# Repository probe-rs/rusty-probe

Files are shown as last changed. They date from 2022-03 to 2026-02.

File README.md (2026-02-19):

# The Rusty Probe

This is an open hardware probe for the Serial Wire Debug (SWD) and JTAG protocol.
Based on the RP2040 MCU.

## Firmware

The firmware is available [here](https://github.com/probe-rs/rusty-probe-firmware) and is open-source.

## Features

- The 10-pin Cortex-Debug connector is used.
- The programming connector is the Tag Connect TC2030, however for just loading firmware the USB bootloader is recommended.
- Castellated vias for all programming pins, power and 2 GPIOs.
- USB-C connector.
- Target 5V and `Vtarget` is protected with an diode circuit to not have current flow from the target to the host.
- The probe support 1.8v - 3.3v signal voltage and can track `Vtarget`.
- The key pin on the Cortex-Debug can be connected to the protected 5V.

The schematic can be found in the GitHub actions, full production files are generated for each commit.

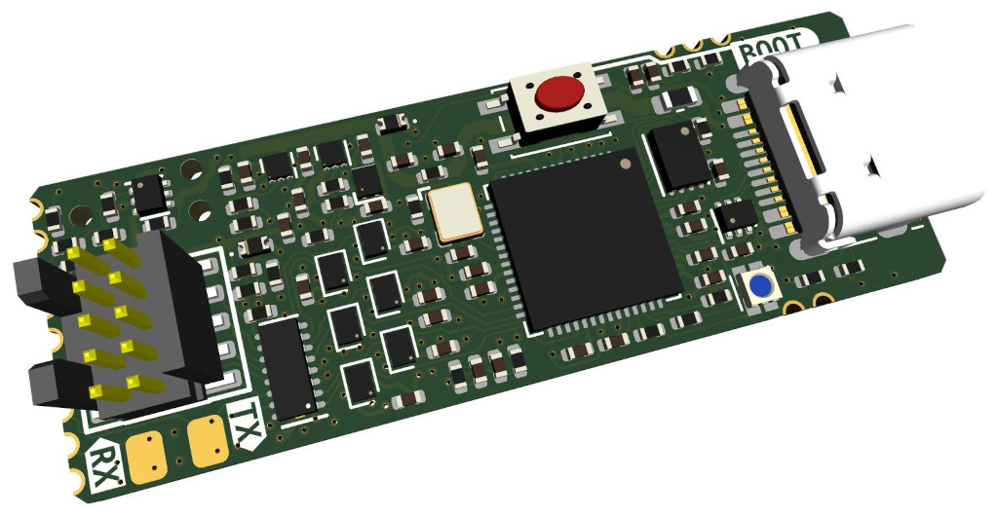
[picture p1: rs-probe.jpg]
probe


## Comparison

Here is a small comparison with a few different probes:

| | Rusty Probe | PicoProbe | Raspberry Pi Debug Probe | STLinkV3 | JLink |
|---|---|---|---|---|---|
| Max speed | 62 MHz | 10 MHz | 10 MHz | 24 MHz | 15 MHz |
| Target interface support| JTAG, SWD, SWO, UART | SWD | SWD, UART | JTAG, SWD, UART, SWO <br>Note: STM8/32 chips only | JTAG, SWD, SWO|
| IO voltage control | 1.8-3.3V | 3.3V | 1.8-3.3V | 1.6-3.3V | 1.6-3.3V somtimes  |
| Type | Open Source & Hardware | Open Source | Open Source Software | Proprietary | Proprietary |
| Language | Rust | C | C | C | C |
| Protocol | CMSIS-DAP | CMSIS-DAP | CMSIS-DAP | Proprietary | CMSIS-DAP |
| Programming connector | Cortex-M Debug 10p | - | JST | Cortex-M Debug 14p | Cortex-M Debug 10p |
| USB speed | 12 MBit/s | 12 MBit/s | 12 MBit/s | 480 MBit/s | 12 MBit/s |

## Where to buy

The probe is available in the [probe-rs shop](https://shop.probe.rs/). But you are free to build one yourself as well!

## License

This work is licensed under [CERN-OHL-P](cern_ohl_p_v2.txt).

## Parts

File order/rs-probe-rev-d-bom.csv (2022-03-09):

Source: | /home/emifre/Git/rs-probe/rs-probe.kicad_sch
Date: | Wed 09 Mar 2022 02:24:04 PM CET
Tool: | Eeschema (6.0.2)
Generator: | /usr/share/kicad/plugins/bom_csv_grouped_by_value.py
Component Count: | 87
Individual Components:
Item | Qty | Reference(s) | Value | LibPart | Footprint | Datasheet | MFPN | Manufacturer | Tolerance
 |  | C1 | 0.1u | Device:C_Small | passive:C_0402 | ~ |  |  | 25V, X7R
 |  | C2 | 2.2u | Device:C_Small | passive:C_0402 | ~ |  |  | 10V, X5R
 |  | C3 | 2.2u | Device:C_Small | passive:C_0402 | ~ |  |  | 10V, X5R
 |  | C4 | 2.2u | Device:C_Small | passive:C_0402 | ~ |  |  | 10V, X5R
 |  | C5 | 0.1u | Device:C_Small | passive:C_0402 | ~ |  |  | 25V, X7R
 |  | C6 | 2.2u | Device:C_Small | passive:C_0402 | ~ |  |  | 10V, X5R
 |  | C7 | 0.1u | Device:C_Small | passive:C_0402 | ~ |  |  | 25V, X7R
 |  | C8 | 0.1u | Device:C_Small | passive:C_0402 | ~ |  |  | 25V, X7R
 |  | C9 | 0.1u | Device:C_Small | passive:C_0402 | ~ |  |  | 25V, X7R
 |  | C10 | 0.1u | Device:C_Small | passive:C_0402 | ~ |  |  | 25V, X7R
 |  | C11 | 0.1u | Device:C_Small | passive:C_0402 | ~ |  |  | 25V, X7R
 |  | C12 | 0.1u | Device:C_Small | passive:C_0402 | ~ |  |  | 25V, X7R
 |  | C13 | 0.1u | Device:C_Small | passive:C_0402 | ~ |  |  | 25V, X7R
 |  | C14 | 0.1u | Device:C_Small | passive:C_0402 | ~ |  |  | 25V, X7R
 |  | C15 | 0.1u | Device:C_Small | passive:C_0402 | ~ |  |  | 25V, X7R
 |  | C16 | 0.1u | Device:C_Small | passive:C_0402 | ~ |  |  | 25V, X7R
 |  | C17 | 0.1u | Device:C_Small | passive:C_0402 | ~ |  |  | 25V, X7R
 |  | C18 | 0.1u | Device:C_Small | passive:C_0402 | ~ |  |  | 25V, X7R
 |  | C19 | 0.1u | Device:C_Small | passive:C_0402 | ~ |  |  | 25V, X7R
 |  | C20 | 0.1u | Device:C_Small | passive:C_0402 | ~ |  |  | 25V, X7R
 |  | C21 | 2.2u | Device:C_Small | passive:C_0402 | ~ |  |  | 10V, X5R
 |  | C22 | 0.1u | Device:C_Small | passive:C_0402 | ~ |  |  | 25V, X7R
 |  | C23 | 0.1u | Device:C_Small | passive:C_0402 | ~ |  |  | 25V, X7R
 |  | C24 | 2.2u | Device:C_Small | passive:C_0402 | ~ |  |  | 10V, X5R
 |  | C25 | 2.2u | Device:C_Small | passive:C_0402 | ~ |  |  | 10V, X5R
 |  | C26 | 2.2u | Device:C_Small | passive:C_0402 | ~ |  |  | 10V, X5R
 |  | C27 | 2.2u | Device:C_Small | passive:C_0402 | ~ |  |  | 10V, X5R
 |  | C28 | 0.1u | Device:C_Small | passive:C_0402 | ~ |  |  | 25V, X7R
 |  | D1 | LTST-C19HE1WT | Device:LED_RGBA | LED_SMD:LED_LiteOn_LTST-C19HE1WT | https://optoelectronics.liteon.com/upload/download/DS22-2008-0044/LTST-C19HE1WT.pdf | LTST-C19HE1WT or ‎IN-S66TBTRGB‎
 |  | D2 | 20V | Device:D_Zener_Small | Diode_SMD:D_SOD-123F | ~ | RBS2MM40CTR
 |  | F1 | Fuse_Small | Device:Fuse_Small | Fuse:Fuse_0603_1608Metric | https://www.bourns.com/docs/Product-Datasheets/mffsmf.pdf | MF-FSMF050X-2
 |  | J1 | USB_C_Receptacle_USB2.0 | Connector:USB_C_Receptacle_USB2.0 | connectors:USB_C_Receptacle_USB4105 | https://www.usb.org/sites/default/files/documents/usb_type-c.zip | C167321 (lcsc.com)
 |  | J2 | Castellated Vias | Connector:Conn_01x09_Female | connectors:1x9_1.5mm_castellated | ~
 |  | J3 | Castellated Vias | Connector:Conn_01x02_Female | connectors:1x2_1.5mm_castellated | ~
 |  | J4 | Castellated Vias | Connector:Conn_01x03_Female | connectors:1x3_1.5mm_castellated | ~
 |  | J5 | tag-connect-swd | connectors:tag-connect-swd | Connector:Tag-Connect_TC2030-IDC-NL_2x03_P1.27mm_Vertical | ~
 |  | J6 | Conn_01x01 | Connector_Generic:Conn_01x01 | connectors:pad_1.5x2.0mm | ~
 |  | J7 | Conn_01x01 | Connector_Generic:Conn_01x01 | connectors:pad_1.5x2.0mm | ~
 |  | J8 | Conn_01x01 | Connector_Generic:Conn_01x01 | connectors:pad_1.5x2.0mm | ~
 |  | J9 | Conn_01x01 | Connector_Generic:Conn_01x01 | connectors:pad_1.5x2.0mm | ~
 |  | Q1 | NTZD3155C or CMLDM3757-TR-PBFREE or DMC2400UV-7 or DMG1016VQ-7 | mosfet:NTZD3155C | sot:SOT-563 | https://www.onsemi.com/pub/Collateral/NTZD3155C-D.PDF
 |  | Q2 | NTZD3155C or CMLDM3757-TR-PBFREE or DMC2400UV-7 or DMG1016VQ-7 | mosfet:NTZD3155C | sot:SOT-563 | https://www.onsemi.com/pub/Collateral/NTZD3155C-D.PDF
 |  | R1 | 1k | Device:R_Small | passive:R_0402 | ~ |  |  | 1%
 |  | R2 | 1k | Device:R_Small | passive:R_0402 | ~ |  |  | 1%
 |  | R3 | 5.1k | Device:R_Small | passive:R_0402 | ~ |  |  | 1%
 |  | R4 | 5.1k | Device:R_Small | passive:R_0402 | ~ |  |  | 1%
 |  | R5 | 1k | Device:R_Small | passive:R_0402 | ~ |  |  | 1%
 |  | R6 | 1k | Device:R_Small | passive:R_0402 | ~ |  |  | 1%
 |  | R7 | 1k | Device:R_Small | passive:R_0402 | ~ |  |  | 1%
 |  | R8 | 1k | Device:R_Small | passive:R_0402 | ~ |  |  | 1%
 |  | R9 | 68k | Device:R_Small | passive:R_0402 | ~ |  |  | 1%
 |  | R10 | 68k | Device:R_Small | passive:R_0402 | ~ |  |  | 1%
 |  | R11 | 68k | Device:R_Small | passive:R_0402 | ~ |  |  | 1%
 |  | R12 | 47k | Device:R_Small | passive:R_0402 | ~ |  |  | 1%
 |  | R13 | 17.4k | Device:R_Small | passive:R_0402 | ~ |  |  | 1%
 |  | R14 | 47k | Device:R_Small | passive:R_0402 | ~ |  |  | 1%
 |  | R15 | 17.4k | Device:R_Small | passive:R_0402 | ~ |  |  | 1%
 |  | R16 | 68k | Device:R_Small | passive:R_0402 | ~ |  |  | 1%
 |  | R17 | 1k | Device:R_Small | passive:R_0402 | ~ |  |  | 1%
 |  | R18 | 68k | Device:R_Small | passive:R_0402 | ~ |  |  | 1%
 |  | R19 | 68k | Device:R_Small | passive:R_0402 | ~ |  |  | 1%
 |  | R20 | 5.1k | Device:R_Small | passive:R_0402 | ~ |  |  | 1%
 |  | R21 | 5.1k | Device:R_Small | passive:R_0402 | ~ |  |  | 1%
 |  | R22 | 68k | Device:R_Small | passive:R_0402 | ~ |  |  | 1%
 |  | R23 | 68k | Device:R_Small | passive:R_0402 | ~ |  |  | 1%
 |  | R24 | 68k | Device:R_Small | passive:R_0402 | ~ |  |  | 1%
 |  | R25 | 68k | Device:R_Small | passive:R_0402 | ~ |  |  | 1%
 |  | R26 | 68k | Device:R_Small | passive:R_0402 | ~ |  |  | 1%
 |  | R27 | 68k | Device:R_Small | passive:R_0402 | ~ |  |  | 1%
 |  | R28 | 1k | Device:R_Small | passive:R_0402 | ~ |  |  | 1%
 |  | R29 | 1k | Device:R_Small | passive:R_0402 | ~ |  |  | 1%
 |  | SW1 | SW_Push | Switch:SW_Push | Button_Switch_SMD:SW_SPST_EVQP2 | ~
 |  | U1 | 74LVC1T45GM,115 | rs-probe:74LVC1T45 | Package_TO_SOT_SMD:SOT-886 | https://www.diodes.com/assets/Datasheets/74LVC1T45.pdf
 |  | U2 | 74LVC1T45GM,115 | rs-probe:74LVC1T45 | Package_TO_SOT_SMD:SOT-886 | https://www.diodes.com/assets/Datasheets/74LVC1T45.pdf
 |  | U3 | W25Q8 | Memory_Flash:W25Q32JVZP | son:USON-8-3x2mm-EP | http://www.winbond.com/resource-files/w25q32jv%20revg%2003272018%20plus.pdf | W25Q80DVUXIE
 |  | U4 | NUF8401MNT4G | interface_esd:NUF8401MNT4G | dfn:DFN-16-1EP_1.6x4mm_P0.5mm | http://www.onsemi.com/pub/Collateral/NUF8401MN-D.PDF
 |  | U5 | STDC14 | connectors:STDC14 | connectors:PinHeader_2x07_FTSH-107-01-L-DV-K |  | FTSH-107-01-L-DV-K
 |  | U6 | RP2040 | rp2040:RP2040 | qfn:RP2040-QFN-56
 |  | U7 | NUF2042XV6T1G | interface_esd:NUF2042XV6T1G | sot:SOT-563 | http://www.onsemi.com/pub/Collateral/NUF2030XV6-D.PDF
 |  | U8 | 74LVC1T45GM,115 | rs-probe:74LVC1T45 | Package_TO_SOT_SMD:SOT-886 | https://www.diodes.com/assets/Datasheets/74LVC1T45.pdf
 |  | U9 | 74LVC1T45GM,115 | rs-probe:74LVC1T45 | Package_TO_SOT_SMD:SOT-886 | https://www.diodes.com/assets/Datasheets/74LVC1T45.pdf
 |  | U10 | 74LVC1T45GM,115 | rs-probe:74LVC1T45 | Package_TO_SOT_SMD:SOT-886 | https://www.diodes.com/assets/Datasheets/74LVC1T45.pdf
 |  | U11 | 74LVC1T45GM,115 | rs-probe:74LVC1T45 | Package_TO_SOT_SMD:SOT-886 | https://www.diodes.com/assets/Datasheets/74LVC1T45.pdf
 |  | U12 | NCP161AMX330TBG | ldo:NCP161AMX300TBG | dfn:UDFN-4_1x1mm_P0.65mm | https://www.onsemi.com/pub/Collateral/NCP161-D.PDF | NCP161AMX300TBG | ON Semiconductor
 |  | U13 | NCP133AMXADJTCG | Regulator_Linear:NCP133AMX100TCG | Package_DFN_QFN:DFN-6-1EP_1.2x1.2mm_P0.4mm_EP0.3x0.94mm_PullBack | http://www.onsemi.com/pub/Collateral/NCP133-D.PDF
 |  | U14 | NCP133AMXADJTCG | Regulator_Linear:NCP133AMX100TCG | Package_DFN_QFN:DFN-6-1EP_1.2x1.2mm_P0.4mm_EP0.3x0.94mm_PullBack | http://www.onsemi.com/pub/Collateral/NCP133-D.PDF
 |  | X1 | 12 MHz | Oscillator:ASCO | crystals:Crystal_SMD_2520-4Pin_2.5x2.0mm | https://abracon.com/Oscillators/ASCO.pdf | ISM95-3251AH-12.000MHZ
Collated Components:
Item | Qty | Reference(s) | Value | LibPart | Footprint | Datasheet | MFPN | Manufacturer | Tolerance
1 | 19 | C1, C5, C7, C8, C9, C10, C11, C12, C13, C14, C15, C16, C17, C18, C19, C20, C22, C23, C28 | 0.1u | Device:C_Small | passive:C_0402 | ~ |  |  | 25V, X7R
2 | 9 | C2, C3, C4, C6, C21, C24, C25, C26, C27 | 2.2u | Device:C_Small | passive:C_0402 | ~ |  |  | 10V, X5R
3 | 1 | D1 | LTST-C19HE1WT | Device:LED_RGBA | LED_SMD:LED_LiteOn_LTST-C19HE1WT | https://optoelectronics.liteon.com/upload/download/DS22-2008-0044/LTST-C19HE1WT.pdf | LTST-C19HE1WT or ‎IN-S66TBTRGB‎
4 | 1 | D2 | 20V | Device:D_Zener_Small | Diode_SMD:D_SOD-123F | ~ | RBS2MM40CTR
5 | 1 | F1 | Fuse_Small | Device:Fuse_Small | Fuse:Fuse_0603_1608Metric | https://www.bourns.com/docs/Product-Datasheets/mffsmf.pdf | MF-FSMF050X-2
6 | 1 | J1 | USB_C_Receptacle_USB2.0 | Connector:USB_C_Receptacle_USB2.0 | connectors:USB_C_Receptacle_USB4105 | https://www.usb.org/sites/default/files/documents/usb_type-c.zip | C167321 (lcsc.com)
7 | 1 | J2 | Castellated Vias | Connector:Conn_01x09_Female | connectors:1x9_1.5mm_castellated | ~
8 | 1 | J3 | Castellated Vias | Connector:Conn_01x02_Female | connectors:1x2_1.5mm_castellated | ~
9 | 1 | J4 | Castellated Vias | Connector:Conn_01x03_Female | connectors:1x3_1.5mm_castellated | ~
10 | 1 | J5 | tag-connect-swd | connectors:tag-connect-swd | Connector:Tag-Connect_TC2030-IDC-NL_2x03_P1.27mm_Vertical | ~
11 | 4 | J6, J7, J8, J9 | Conn_01x01 | Connector_Generic:Conn_01x01 | connectors:pad_1.5x2.0mm | ~
12 | 2 | Q1, Q2 | NTZD3155C or CMLDM3757-TR-PBFREE or DMC2400UV-7 or DMG1016VQ-7 | mosfet:NTZD3155C | sot:SOT-563 | https://www.onsemi.com/pub/Collateral/NTZD3155C-D.PDF
13 | 9 | R1, R2, R5, R6, R7, R8, R17, R28, R29 | 1k | Device:R_Small | passive:R_0402 | ~ |  |  | 1%
14 | 4 | R3, R4, R20, R21 | 5.1k | Device:R_Small | passive:R_0402 | ~ |  |  | 1%
15 | 12 | R9, R10, R11, R16, R18, R19, R22, R23, R24, R25, R26, R27 | 68k | Device:R_Small | passive:R_0402 | ~ |  |  | 1%
16 | 2 | R12, R14 | 47k | Device:R_Small | passive:R_0402 | ~ |  |  | 1%
17 | 2 | R13, R15 | 17.4k | Device:R_Small | passive:R_0402 | ~ |  |  | 1%
18 | 1 | SW1 | SW_Push | Switch:SW_Push | Button_Switch_SMD:SW_SPST_EVQP2 | ~
19 | 6 | U1, U2, U8, U9, U10, U11 | 74LVC1T45GM,115 | rs-probe:74LVC1T45 | Package_TO_SOT_SMD:SOT-886 | https://www.diodes.com/assets/Datasheets/74LVC1T45.pdf
20 | 1 | U3 | W25Q8 | Memory_Flash:W25Q32JVZP | son:USON-8-3x2mm-EP | http://www.winbond.com/resource-files/w25q32jv%20revg%2003272018%20plus.pdf | W25Q80DVUXIE
21 | 1 | U4 | NUF8401MNT4G | interface_esd:NUF8401MNT4G | dfn:DFN-16-1EP_1.6x4mm_P0.5mm | http://www.onsemi.com/pub/Collateral/NUF8401MN-D.PDF
22 | 1 | U5 | STDC14 | connectors:STDC14 | connectors:PinHeader_2x07_FTSH-107-01-L-DV-K |  | FTSH-107-01-L-DV-K
23 | 1 | U6 | RP2040 | rp2040:RP2040 | qfn:RP2040-QFN-56
24 | 1 | U7 | NUF2042XV6T1G | interface_esd:NUF2042XV6T1G | sot:SOT-563 | http://www.onsemi.com/pub/Collateral/NUF2030XV6-D.PDF
25 | 1 | U12 | NCP161AMX330TBG | ldo:NCP161AMX300TBG | dfn:UDFN-4_1x1mm_P0.65mm | https://www.onsemi.com/pub/Collateral/NCP161-D.PDF | NCP161AMX300TBG | ON Semiconductor
26 | 2 | U13, U14 | NCP133AMXADJTCG | Regulator_Linear:NCP133AMX100TCG | Package_DFN_QFN:DFN-6-1EP_1.2x1.2mm_P0.4mm_EP0.3x0.94mm_PullBack | http://www.onsemi.com/pub/Collateral/NCP133-D.PDF
27 | 1 | X1 | 12 MHz | Oscillator:ASCO | crystals:Crystal_SMD_2520-4Pin_2.5x2.0mm | https://abracon.com/Oscillators/ASCO.pdf | ISM95-3251AH-12.000MHZ

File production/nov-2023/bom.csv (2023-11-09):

Reference | Value | Footprint | MFPN | Tolerance | Qty
C1, C5, C7-C20, C22, C23, C28 | 0.1u | passive:C_0402 |  | 25V, X7R | 19
C2-C4, C6, C21, C24-C27, C29, C30 | 2.2u | passive:C_0402 |  | 10V, X5R | 11
D1 | LTST-C19HE1WT | LED_SMD:LED_LiteOn_LTST-C19HE1WT | LTST-C19HE1WT or ‎IN-S66TBTRGB‎ |  | 1
D2, D3 | 20V | Diode_SMD:D_0402_1005Metric | SBA0520Q or similar |  | 2
F1 | MF-FSMF050X-2 | Fuse:Fuse_0603_1608Metric | MF-FSMF050X-2 |  | 1
FB1 | BLM15AX601SN1D | passive:R_0402 | BLM15AX601SN1D |  | 1
J1 | USB_C_Receptacle_USB2.0 | connectors:USB_C_Receptacle_USB4105 | C167321 (lcsc.com) |  | 1
Q1 | NTZD3155C or CMLDM3757-TR-PBFREE or DMC2400UV-7 or DMG1016VQ-7 | sot:SOT-563 | NTZD3155C or CMLDM3757-TR-PBFREE or DMC2400UV-7 or DMG1016VQ-7 |  | 1
R1, R13, R15, R28 | 17.4k | passive:R_0402 |  | 1% | 4
R2, R5-R7, R17 | 1k | passive:R_0402 |  | 1% | 5
R3, R4, R8, R20, R29 | 5.1k | passive:R_0402 |  | 1% | 5
R9, R11, R12, R14, R16, R19, R21, R27 | 47k | passive:R_0402 |  | 1% | 8
R10, R18, R22-R24, R26 | 1Meg | passive:R_0402 |  | 1% | 6
R25 | 15k | passive:R_0402 |  | 1% | 1
SW1 | EVQ-P2002W | Button_Switch_SMD:SW_SPST_EVQP2 | EVQ-P2002W |  | 1
U1, U2, U8-U11 | 74LVC1T45GM,115 | Package_TO_SOT_SMD:SOT-886 | 74LVC1T45GM,115 |  | 6
U3 | W25Q8 | son:USON-8-3x2mm-EP | W25Q80DVUXIE |  | 1
U4 | NUF8401MNT4G | dfn:DFN-16-1EP_1.6x4mm_P0.5mm | NUF8401MNT4G |  | 1
U5 | CortexDebug | connectors:PinHeader_2x05_FTSH-105-01-L-DV-K | FTSH-105-01-L-DV-K |  | 1
U6 | RP2040 | qfn:RP2040-QFN-56 | RP2040 |  | 1
U7 | NUF2042XV6T1G | sot:SOT-563 | NUF2042XV6T1G |  | 1
U12-U14 | NCP133AMXADJTCG | Package_DFN_QFN:DFN-6-1EP_1.2x1.2mm_P0.4mm_EP0.3x0.94mm_PullBack | NCP133AMXADJTCG |  | 3
X1 | 12 MHz | crystals:Crystal_SMD_2520-4Pin_2.5x2.0mm | ISM95-3251AH-12.000MHZ |  | 1

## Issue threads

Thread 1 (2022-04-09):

Form factor consideration

code-db, 2022-04-09:
For the rusty-probe to be used as a mezzanine board on a base card, it would ideally be soldered to a PCB adapter with a standard pitch. Has an adapter PCB been made? What considerations would that adapter/rusty-probe require?

The bottom of the rusty-probe PCB contains configuration details in the silk screen and exposed copper pads. That information & functionality would no longer be accessible if the rusty-probe was used on an adapter PCB.

korken89, 2022-11-28:
The solder-in option is if you want to have it on e.g. a production unit, this is how we use the solder in option.
Plus the STLinkv3 does similarly (where we got the idea from).

However no more thought than that has been put into this.

korken89, 2022-11-29:
Oh yeah, another point on this.
If one does not want to pay for the castellated vias, it's fine to just delete them before sending to production as well.

Closed 2024-11-10.

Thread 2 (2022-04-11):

Voltage regulators

diggit, 2022-04-11:
Hi,
I was looking on schematic and voltage regulators caught my eye.

NCP133BMXADJTCG (U13, U14) is "End of Life" part https://www.onsemi.com/products/power-management/linear-regulators-ldo/ncp133. It's difficult to obtain from major distributors.

Why is U12 different from U13 and U14? It would make sense to use same part from BOM minimization point of view.

korken89, 2022-11-28:
There are issues as there are requirements on the U13, U14 being adjustable.
I'm looking into replacing these though.

korken89, 2022-11-28:
I have updated the design to they "sister" component to solve this issue.

Closed 2022-11-28.

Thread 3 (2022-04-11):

Level translation

diggit, 2022-04-11:
I've seen several other probes with level shifters, and tracking `T_VCC` to get `TRANS_VCC` is not very common. It puts high requirements on regulators (very low drop) and probe itself.

Common approach, was to use low (quiescent) power level translators and power them directly from `T_VCC`. Such option is eg. AXP logic from NXP. `74AXP1T45` has quiescent current below 1uA. Dynamic power consumption would be covered by caps and one voltage regulator could be omitted (U14).

Is there some other reason for current design?

korken89, 2022-11-28:
Hi, sorry for not coming to this.
Could you expand on the issue, I don't see what you mean?

The reason for this is that we don't have any guarantee on the power delivery on `T_VCC`, and throwing in an extra LDO to make it a non-issue was a no-brainer to me.
Debugging intermittent power issues on `T_VCC` sounds like a nightmare to me, hence the current design.

diggit, 2022-12-05:
Even though, you are saving several uA being drained from T_VCC by supplying level translators separately, you are adding extra current drain by having extra voltage divider R14/R15, consumption from T_VCC is increased by 50uA.
Having this "tracking" regulator for level translators and you are adding some delay between T_VCC and level translators using it.
There are devices which dynamically change their VCC to conserve power.
For comparison, J-link probes just feed T_VCC into level translators VCC. I never had issue there. J-link base consumes 30 uA from T_VCC when there is 3V3.
btw Mouser tells NCP133BMXADJTCG is NRND.

I just don't see reason to add this extra complexity into circuit for no obvious gain.

korken89, 2022-12-06:
Hi, thank for the comments.

> Even though, you are saving several uA being drained from T_VCC by supplying level translators separately, you are adding current drain by having extra voltage divider R14/R15, consumption from T_VCC is increased by 50uA.

If someone really needs that we load `T_VCC` less it's fine to replace the voltage divider with larger value resistors, `1 Meg` should do fine for example.
However the leakage through the translators and target pull-up will be much larger than the contribution of the divider.

> By having this "tracking" regulator for level translators and you are adding some delay between T_VCC and level translators using it.
> There are devices which dynamically change their VCC to conserve power.

Indeed there will be a delay, however it is quite small. About a millisecond if I remember correctly with the current setup.
I don't see that this would cause issues, as when the target goes into a low power state the debug unit will be disabled.
The important part then is that RESET continues to work, and it's an open-drain output which is independent to target voltage.

>  btw Mouser tells NCP133BMXADJTCG is NRND.

This part is no longer used in the design. Please have a look at the latest version for updated parts.

> I just don't see reason to add this extra complexity into circuit for no obvious gain.

You can have a look at my previous reply for why and the gain it has.
The other part is when targets don't have `T_VCC` connected, which is common for breakout boards - then you can still set the level manually.

I obviously see a gain, you don't - however you have not convinced me that there is an issue with the current design.
If you want to see something changed I need clear pros-cons.

diggit, 2022-12-06:
>This part is no longer used in the design. Please have a look at the latest version for updated parts.

I just looked into schematic linked in readme in master branch.

> I don't see that this would cause issues, as when the target goes into a low power state the debug unit will be disabled.

1. eg STM32 can be told to leave debug unit powered in deep sleep, so it does not apply universally
2. There are boards with always on LDO (eg 2V) and with DC/DC (eg. 3.3V), outputs connected together.  DC/DC is enabled when there is needed more power for target (and other components.) Yeah, due to capacities on power rails, these changes won't be fast...

Also, is this tracking done as closed loop or open loop? Closed loop puts some requirements on regulator (stability), open loop requires extra calibration.

> however you have not convinced me that there is an issue with the current design.
If you want to see something changed I need clear pros-cons.

That is right attitude. Let me try a bit more.

My attitude: "When there is no gain from something, why have it there?"

> I obviously see a gain, you don't.

> You can have a look at my previous reply for why and the gain it has.

Previous reply
> The reason for this is that we don't have any guarantee on the power delivery on T_VCC, and throwing in an extra LDO to make it a non-issue was a no-brainer to me.
Debugging intermittent power issues on T_VCC sounds like a nightmare to me, hence the current design.

What could cause those "intermittent power issues on T_VCC"? Can you describe such situation? I am genuinely interested.

Maybe I am just missing something here or it just never occurred to me.

In the end, you have total control over this project and I am just some stranger on the internet. :slightly_smiling_face:

korken89, 2022-12-06:
Hi, thanks for the comments!

> I just looked into schematic linked in readme in master branch.

There is no schematic in the master branch anymore, you must have looked at an old version.
The README now points to the GHA where schematics are generated.
You would have to look at the latest commits' artifacts to get the schematic now.

There were some old PDF exports in the repo, I deleted them now.

> Also, is this tracking done as closed loop or open loop? Closed loop puts some requirements on regulator (stability), open loop requires extra calibration.

It is open loop, but you only need to be accurate enough so the internal ESD diodes do not start conducting which generally means you need to be within +/- 0.5V. In my testing we are within 20 mV using the ideal formula so I see no need for calibration.

> What could cause those "intermittent power issues on T_VCC"? Can you describe such situation? I am genuinely interested.

Absolutely as this has happened for me. Any oxidation on `T_VCC`'s pad is generally enough to start having issues.
It's fine until the translators switch at which point the `T_VCC` droops. And I do not want this to be an issue.

diggit, 2022-12-06:
> Any oxidation on `T_VCC`'s pad is generally enough to start having issues.
It's fine until the translators switch at which point the `T_VCC` droops. And I do not want this to be an issue.

I see. Higher resistance of `T_VCC` line is definitely possible and could cause issues, but that applies to all other signals too.
I'd rather be notified in such case than have HW silently working around it, because if there is issue with `T_VCC`, other signals could have some issues too and there is no workaround for them...

My point is, this added complexity solves possible issue with only one "signal". So you have to keep care of your debug connections anyway.

<hr/>

Looking at regulators U13/U14, NCP133AMXADJTCG is used. I noticed that these regulators can handle only 3.6 V as max output.
There are 5V capable targets, for example [Nuvoton Cortex M0](https://www.nuvoton.com/products/microcontrollers/arm-cortex-m0-mcus/).

What about same regulator for all 3 power rails? It would reduce BOM.

Do sou want to discuss these in separate issue?

korken89, 2022-12-07:
On the `T_VCC` issue vs other signal, this is handled by the JTAG/SWD communication and its checksum.
So you'll get errors if the communication is shaky (CRC error). The only signal not having a backup was `T_VCC` to the translators.

On the 5V support, this is not an aim with this board - it's designed around 3.3V maximum.
A different board could be made with "extended voltage range".

I checked trying to consolidate the BOM before, and it was not possible due to space.
Now it can probably be done, one will get a new resistor value to the BOM instead.

diggit, 2022-12-07:
> On the 5V support, this is not an aim with this board - it's designed around 3.3V maximum.
A different board could be made with "extended voltage range".

It's a pity. The only necessary changes would be different regulators and dividers.

Anyway, this is probably resolved issue, closing.

Closed 2022-12-07.

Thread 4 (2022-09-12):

JLC assembly compatible BOM

allexoll, 2022-09-12:
having a BOM compatible with JLC assembly service would be pretty helpfull for accessibility.

Might have a look later if I find the time.

korken89, 2022-11-28:
It would be awesome! I'd also like there to be such, ping me if you start looking and I can give feedback.
I think even if we need to update the design it would be worth it.

allexoll, 2022-11-28:
#6 should be a start, but I have not ordered some using that ( no stock on any semiconductor anyway...)

korken89, 2022-11-28:
Indeed, I have no idea how lcsc works so finding a suitable LDO should be the only thing that needs fixing right?

allexoll, 2022-11-28:
no, what I meant is that when I ordered my small batch, they did not have any ic in stock, mostly due to shortage. From what i understand from JLC/LCSC, you can order the parts in advance for them to have them in stock when you assemble it. it just was not worth it for the 10 I built, and for those I only asked them to place the passive (Rs, Cs) and a few others: Osc, type-c connector, and so on. see photo:
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

I have assembled one with components I ordered from mouser, but I did not have time to test it yet.

korken89, 2022-11-28:
Ahhh, I understand. Looks great!

FYI - I just pushed updates to the design so we can use the active discharge version of NCP133 (which seems to be easy to get).
It should not impact the code though, so this board should work fine in the end.

korken89, 2022-11-28:
Also I added CI actions to generate gerbers, images of PCB etc for future use.

korken89, 2024-11-10:
I gave this a look again, there seems to be a lot better part selection on JLCPCB now - I'm quite sure one can adapt the board into an JLCPCB friendly version.

berkus, 2024-12-06:
We have a JLCPCB bom now, so I guess this can be closed?

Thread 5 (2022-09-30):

UART pinout for vcp is incorrect

allexoll, 2022-09-30:
currently dir_vcp_rx/tx is on gpio25/24, and vcp_rx/tx on 18/19.

The issue is that 18/19 only have cts/rts capabilities on the rp2040, but not rx/tx.

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

but gpio24/25 have uart1 rx/tx capabilities:
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

i think just switching the two pinset would be enough for VCP to work. I currently have a start of impl for the vcp (using core1 since DMA has not yet landed in the hal), but it will need the correct pins for this to work.

korken89, 2022-10-09:
Hi, thanks for reporting!

I have moved the pins to 20 and 21 in the latest commit:
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

Closed 2022-10-09.

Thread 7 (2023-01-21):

Readme link to shop is broken

tgross35, 2023-01-21:
Hello,

It looks like the link in the readme, https://shop.probe.rs/, is broken

It comes up with a security warning then 403 forbidden if you continue to navigate to the site

Yatekii, 2023-01-21:
I disabled the shopify shop to save money while we cannot produce more probes due to chip shortage. I updated the README, thank you :)

tgross35, 2023-01-21:
Oh no, well thanks for the context.

Out of curiosity, what are the blocker parts? Looks like the RP2040 is back in stock on Digi https://www.digikey.com/en/products/detail/raspberry-pi/SC0908-7/14306009?src=raspberrypi, I don't think anything else would be beyond an easy alt

korken89, 2023-01-21:
The link is for the previous version based on STM32, this probe is still under testing. :)

As soon as it's ready we'll add the link back!

tgross35, 2023-01-21:
Oh cool, I didn’t realize there was an updated part!

Fwiw if you ever need an extra hand for a schematic review / sourcing / whatever, feel free to ping me since that’s my day job (know it’s unlikely for this tiny project, but 🤷 doesn’t hurt)

Yatekii, 2023-01-21:
Reviews are always welcome and new hardware projects & improvements :) I think the hardware team atm is pretty much just @korken89 even tho we have some others contributing :)

The entire project lives of OS contributions, so please feel free to contribute whenever you feel like it :)

korken89, 2023-01-22:
@tgross35 hit me up on matrix with name and shipping address and I'll send you a prototype. :)

Closed 2023-01-21.

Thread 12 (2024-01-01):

Should the DTR/RTS pins of the virtual serial port be adapted

HalfSweet, 2024-01-01:
For some MCUs that rely on using the serial port for downloads, the use of RTS/DTR for auto-reset into their own bootloader is clearly needed, and for the debugger, we just need to add two more IO ports for output. Will we consider doing this in the rusty-probe later on?

Yatekii, 2024-01-01:
I am not sure what exactly you want, but if you want to flash via serial, you can use a serial adapter? :)

HalfSweet, 2024-01-01:
Yes, but I think rusty-probe could be more versatile if it had full USB to UART functionality.

For some MCUs that need UART for flash, such as the ESP32 the general practice is to use the RTS and DTR signals from the serial port as trigger flags

korken89, 2024-11-10:
That's a good future upgrade path, I'll keep it in mind!

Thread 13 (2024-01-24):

shop info, more shipping options

WizardUli, 2024-01-24:
It would be nice for the shop to have some more info like e.g. where it is shipping from. I suppose it is not Europe and in that case it would be nice to have shipping options like DHL Express which could handle taxes and customs duty for me.

Yatekii, 2024-02-01:
You can let me know via email or on Matrix if you want special shipping. But it's more effort for me to ship with a different provider and I am not keen for more work ^^

WizardUli, 2024-02-01:
I've already ordered two probes accepting I'll have to deal with VAT and duties and horrible Czech Post which usually takes more time to deliver something inside CZ than it takes for it to arrive into CZ even from the other side of the globe.

Yatekii, 2024-02-01:
2 probes fly under the VAT limit in Switzerland (where I ship from). Nut sure what the limit is for CZ.

Closed 2024-02-01.

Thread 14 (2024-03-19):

Board file artifacts expire

kC0pter, 2024-03-19:
First of all, awesome project especially with having open source hardware. Big fan of it.

I love the fact that the pipeline builds the necessary board and assembly files for everything.
I noticed that the artifacts of the last pipeline run have expired.

It might be a good idea to either not let the latest artifact expire or "deploy" them to the release/tags section so they can be downloaded from there.

berkus, 2024-05-03:
Indeed, wanted to check out the schematics only to find out that last successful build was over 6 months ago and all artifacts have since perished.

korken89, 2024-11-10:
Thanks for the hint! Sorry for that happening. I'll see if I can revive the artifacts for the current board design and push a release.

berkus, 2024-11-10:
@korken89 you need help with a little bit of more robust setup? I think the build artifact should be published as a release (attached to the generated release as a binary), then it will be preserved indefinitely.

korken89, 2024-11-10:
I'd love some help :) I've never really tried the release workflow together with artifacts.

berkus, 2024-11-12:
@korken89 check it out.

Closed 2024-11-13.

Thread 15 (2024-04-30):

Target support of "any" is too ambiguous and incorrect. List of supported debugging protocols/interfaces would be better.

acedogblast, 2024-04-30:
The comparison chart on the README has "any" for what targets are supported for all probes listed other than the STLinkV3. This is too broad and also not true. A list of supported debugging protocols/interfaces will provide a more accurate description of the capabilities of the probes.

From what I understand the Rusty Probe currently only supports JTAG and SWD (Serial Wire Debug for ARM chips) with support for Serial Wire Output (SWO) and Virtual COM Port (VCP) a WIP. Also where is UART support?

These protocols/interfaces are the most common but lesser known protocols like WCH's single wire debug (for RISC-V CH32Vxxx micro-controllers) is not included. Therefor the target support value of "any" is incorrect and misleading.

I can send a pull request to correct this error.

acedogblast, 2024-04-30:
What probe is "PicoProbe"? It it just a Raspberry PI Foundation's Pico line of RP2040 dev boards flashed with the Raspberry Pi Debug Probe firmware?

korken89, 2024-11-10:
Sorry, this issues and PR got forgotten. Can you update the PR from conflicts and I'll merge it?

acedogblast, 2024-11-11:
It seems there has not been any changes to master since I submitted the pull. So I just kept my changes.

berkus, 2024-11-11:
Thanks!

Closed 2024-11-14.

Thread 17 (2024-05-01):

Understanding the Target voltage feedback circuit and possible modification for 5V targets.

acedogblast, 2024-05-01:
Hello I wanted to ask about the functionality of the target voltage feedback circuit. I consider my knowledge in electrical engineering is mostly in the intermediate hobbyist level. From what I can understand in the schematic and reading the data sheet of the LDOs used, the feedback circuit controls the output voltage of the LDO. Traditionally it is a simple voltage divider circuit with simple algebra math to calculate the resistor values. According to the LDO's datasheet the feedback voltage is 0.8V. With just the top and bottom resistors (47K and 17.4K) the output voltage would be 2.96V.
However in this design we have an additional voltage source provided by the PWM signal from the RP2040. This PWM signal is passed through 2 low-pass RC filters in series to convert PWM to a DC signal with a range between 0.0V to 3.3V forming a rudimentary digital to analogue converter. This is where my EE knowledge is insufficient on how this DC signal is handled.

My best guess is this DC signal is like another "top voltage feed" for another voltage divider that shares the bottom resistor. Lets use R14, R15, and R16 in the Rusty Probe for analysis. The label "T_VCC" is both the output of U14 LDO and possibly the main power from the target. The label "VS_T" is the DC signal from the PWM DAC. Lastly the label "ADJ_T" is the midpoint of the voltage divider and is connected to the feedback pin of the LDO.

Initially the LDO would provide 2.96V which is lower than 3.3V (assuming that is the target's voltage). The RP2040 senses the lower voltage though a separate voltage divider and starts to create a lower DC output from the DAC circuit (lets say 2.6V). I am assuming that this 2.6V signal is able to overpower the original 2.96V because it sinks the current which results in a lower than 0.8V feedback signal to the LDO. This results in the LDO to increase the output voltage to compensate.

Now to the calculations of the voltage divider resistors. I do not have matlab nor have any experience using it or reading matlab code. Therefor I am asking for your help on understanding the calculations needed to pick the right resistor values.

The original design of the Rusty Probe is for targets with a signal voltage at or below 3.3V it would nice to make a version that can also support 5V signals. I have read the data sheets of the LDOs, the level shifters, and the ESD/EMI part U4. It would seem that the only limitation with the current BOM is that the LDOs have a maximum output of 3.6V. A possible replacement LDO that I have found is Diodes Inc. AP7366EA-SN-7 as it has very similar characteristics. It has the same 0.8V feedback voltage as the existing LDOs (NCP133AMXADJTCG) and a lower Iq current of 60uA. Dropout voltage is a bit higher at the same output currents but should be fine since 5V high signals have a larger tolerance range.

I would like to make this 5V compatible probe use the same firmware as the Rusty Probe. From what I have read in the firmware code, modifications will be needed to add 5V support but I'm sure it can be done in a way to maintain compatibility with existing Rusty Probes. From a hardware perspective the existing Rusty Probes can safely receive 5V signals but are not able to send them. I will follow up on firmware compatibility on a different issue on the firmware repository.

Finally I would like to express my thanks for your work and effort but into this project. I hope we can collaborate to further improve this project.

korken89, 2024-05-04:
Hi, thanks for the interest!

The calculations and possible output voltages are in the GNU Octave scripts in the repo that can be run with `octave-cli math/find_resistors.m`.
In here you can also change the resistors OR ask the script to find resistors for a new desired output range. The script is quite capable. :)
The first half is for solving, and the second half of the script is for plugging in "selected resistors" - as the solver does not follow E96 for example.

When it comes to 5V support there are 3 things that need to change:

1. The LDOs as you have noticed.
2. Voltage dividers for measuring voltage with the MCU.
3. The voltage translator ICs that have a requirement of Output signal <= Input signal (RP2040 3.3V)

And that should be it!

BR Emil

acedogblast, 2024-05-04:
Thanks for the information. The current voltage divider for `T_VCC_MEAS` uses two 47K resistors which would divide the voltage in half. Half of 5V is 2.5V which should be fine the RP2040's ADC since the max voltage for the ADC input is 3.3V. Why do you say it needs to be changed?

korken89, 2024-05-05:
That's correct, I mixed it with another design.

acedogblast, 2024-05-10:
Another concern that I have found is that ~RESET for the target is not handled through a voltage translator. It is only pass through the NUF8401 100ohm chip then to the RP2040. A 5V native target could send 5V into the RP2040. In the firmware it does not seem that we are using ~RESET as an input but only as a "open drain" output.

Also to note an open-drain output is an output that either a floating/unconnected hence "open" or the output is driven to GND which "drains" the output pin. Often such an output has a pull-up resistor to ensure the output is either high or low but in this case of the Rusty Probe it is not needed.

korken89, 2024-11-10:
If there are no more questions here I'm going to close this issue. Feel free to reopen if there are more questions!

Closed 2024-11-10.

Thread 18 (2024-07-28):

https://shop.probe.rs is a scam?

WizardUli, 2024-07-28:
I ordered 2 rusty-probes on 24.1.2024 from the shop in https://github.com/probe-rs/rusty-probe/blame/d55237719e234000097c2dac1f8991a65e5a82e6/README.md#L41 got an order confirmation from shopify and since then there has been no communication whatsoever.

I would have understood if there were an email after a couple of months saying that there were problems with manufacturing or logistics or that the current hardware revision was too buggy and you were waiting for fixes and stabilization or that you had underestimated manufacturing of a real world product and could not fulfill the orders at all.
But this is either an unprofessional conduct or an outright scam.

Yatekii, 2024-07-28:
Many people have asked me directly and I tried to always offer insight as best as possible. Unfortunately I do this in my sparetime for your benefit and no financial gain and it's hard for me to always send out emails with ETAs that I cannot actually promise because as you can see we still did not ship and all the timings are flakey. If you asked me for your money back, you would have it tomorrow.

WizardUli, 2024-07-28:
See, having this information at the shop instead of "lead time couple of weeks" would be enough. Any update at all even changing the wording to "a couple of months" would be ok.

If you ever get the production running well, consider raising the prices or just offering pricier variants where the difference goes into supporting you. Good luck.

Yatekii, 2024-07-28:
When I first put this up, it was a couple weeks. And estimate was always a couple weeks. Unfortunately I cannot guess all the unforeseen circumstances in advance.
I had plenty of people claim that the shop page did not state anything about delivery delays - which it does - making it obvious that putting more info there would not really help, especially since all the info I can put at any point in time is: The probes are being shipped in a couple weeks. After all the production shenanigans (samples being bad, Chinese new year, second batch of samples being lost in Swedish post for one month, etc) the probes were estimated to arrive at my place end of May, but then they were sent to Sweden and made a detour and I got them 2 weeks ago. They will be shipped this week.

trembel, 2025-02-17:
Would it be possible to put on kitspace, s.t. one-click orders could be out-sourced?

Closed 2024-07-28.

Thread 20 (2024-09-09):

rusty-probe enumerates two USB devices

igiona, 2024-09-09:
At least on windows (I did not test other OSs yet), the rusty-probe enumerates as two devices with the same serial number.
For this reason, `probe-rs` requires additional parameters `--probe 1209:4853` even though I actually have only one probe connected.
When developing and working via command-line it's quite annoying.

Is there a way to avoid this double-enumeration?
Why it's there in the first place? I don't see for me a way to select "the other" probe, since PID and VID are the same...

Yatekii, 2024-09-09:
cc @korken89

igiona, 2024-09-09:
Additional information, this the output of `probe-rs list` :

```shell
$ probe-rs list
The following debug probes were found:
[0]: Rusty Probe with CMSIS-DAP v1/v2 Support (VID: 1209, PID: 4853, Serial: DC645020138A1122EF4014, CmsisDap)
[1]: HS-Probe CMSIS-DAP v1 Interface (VID: 1209, PID: 4853, Serial: dc645020138a1122ef4014, CmsisDap)
```

jannic, 2024-10-01:
A similar thing has been mentioned on matrix a while ago: https://matrix.to/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

Dirbaio diagnosed it as probably caused by https://github.com/kevinmehall/nusb/issues/22

korken89, 2024-10-04:
That's odd, how do you get this to happen? I was not able to reproduce on any of my computers, but it seems like two interfaces have different descriptions.
I'll look into it during my update of the HAL.

igiona, 2024-10-06:
> That's odd, how do you get this to happen? I was not able to reproduce on any of my computers, but it seems like two interfaces have different descriptions.
> I'll look into it during my update of the HAL.

Nothing special to be honest.
I'm using a USB HUB, hard to believe but maybe it's because of that?
My PC has WSL enabled, maybe the USB drivers get messed up?
I'll try on other machines as well and let you know.

korken89, 2024-10-06:
Ah sorry, I did not know you ran on Windows.
I'll dig up a Windows computer to test on :)

abelREK, 2024-11-05:
I can confirm that this also happens on windows.

korken89, 2024-11-10:
I've checked now and we only register one device, however it has multiple interfaces. Not sure why that would be a problem. To me it seems like an `nusb` issue on Windows, has anyone opened an issue at `probe-rs`? The interface logic seems like it needs special handling in Windows or maybe `nusb` needs some looking into. 😅

igiona, 2024-11-10:
> I've checked now and we only register one device, however it has multiple interfaces. Not sure why that would be a problem. To me it seems like an `nusb` issue on Windows, has anyone opened an issue at `probe-rs`? The interface logic seems like it needs special handling in Windows or maybe `nusb` needs some looking into. 😅

Thank you for looking into it.
If it is a would be an USB driver issue, other probes would suffer from the same issue no?
I have a AK-CMSIS-DAP here, and it enumerates only one...

```bash
$ probe-rs.exe list
The following debug probes were found:
[0]: Rusty Probe with CMSIS-DAP v1/v2 Support (VID: 1209, PID: 4853, Serial: DC645020138A1122EF4014, CmsisDap)
[1]: AK-CMSIS-DAP (VID: 10c4, PID: 8b54, Serial: AKA5130B, CmsisDap)
[2]: HS-Probe CMSIS-DAP v1 Interface (VID: 1209, PID: 4853, Serial: dc645020138a1122ef4014, CmsisDap)
```

korken89, 2024-11-10:
Ah no, I see the confusion, but the difference is that the probe is one device with two interfaces. It exposes a CMSIS-DAP v1 and v2 at the same time so both old and new tooling can use it. The issue though is that probe-rs, AFAIK, hides redundant interfaces of probes and only shows the v2. And in here lies the issue because on Windows, for some reason, the interfaces don't get the same serial ID. Hence why it can be fixed in probe-rs by doing comparison that is not case sensitive, or in nusb to fix the serial ID output.

In your case though I would just remove the V1 interface, it would be the easiest solution. Maybe it's worth adding a feature gate to enable the dual interface that's enabled by default? It would make it easier.

igiona, 2024-11-10:
> Ah no, I see the confusion, but the difference is that the probe is one device with two interfaces. It exposes a CMSIS-DAP v1 and v2 at the same time so both old and new tooling can use it. The issue though is that probe-rs, AFAIK, hides redundant interfaces of probes and only shows the v2. And in here lies the issue because on Windows, for some reason, the interfaces don't get the same serial ID. Hence why it can be fixed in probe-rs by doing comparison that is not case sensitive, or in nusb to fix the serial ID output.
>
> In your case though I would just remove the V1 interface, it would be the easiest solution. Maybe it's worth adding a feature gate to enable the dual interface that's enabled by default? It would make it easier.

They are the same serial, but a different case.
Likely probe-rs does a full string match on the serial number, relaxing the check could solve the issue I guess.
I'll open an issue on probe-rs soon.

> In your case though I would just remove the V1 interface, it would be the easiest solution. Maybe it's worth adding a feature gate to enable the dual interface that's enabled by default? It would make it easier

With this you mean "customizing" the FW of the rusty probe, right?

korken89, 2024-11-10:
> With this you mean "customizing" the FW of the rusty probe, right?

Correct. It's a small change to perform.

Closed 2024-11-22.

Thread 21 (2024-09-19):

3.3V voltage level without T_VCC

Murmele, 2024-09-19:
Hello,

I have a design with only SWDIO and SWDCLK but no T_VCC. Because of that it is not possible to use the probe for debugging.

One possibility would be to fake the T_VCC externally by applying 3.3V.
Is there another way to set the output voltage by hardware without changing the firmware of the probe it self using probe-rs?

Murmele, 2024-09-19:
I tested with the master version compile my self, and it seems to behave differently

Closed 2024-09-19.

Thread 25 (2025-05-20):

Add CPL file to output files

krokosik, 2025-05-20:
It would be nice to order the probe with assembly. While I can do this manually in KiCAD, maybe it could be added to the pipeline?

(BTW, are there plans to restock the official store?)

Closed 2025-05-20.

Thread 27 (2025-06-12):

Mounting Hole

felipebalbi, 2025-06-12:
If you guys ever come up with a v2, please consider adding a mounting hole which would help securing the board to an enclosure.

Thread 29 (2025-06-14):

Is lead time on shop.probe.rs page accurate?

WesleyAC, 2025-06-14:
On the [shop page](https://shop.probe.rs/products/rusty-probe) it states:

> Lead time is a couple weeks - we are manufacturing currently.

But it's said this since [at least late 2023](https://web.archive.org/web/20231207010433/https://shop.probe.rs/products/rusty-probe).

Sorry if this isn't the right place to ask this, but what's the actual lead time if purchased from that page? Was the production run ever made?

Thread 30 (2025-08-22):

hs-probe

usbalbin, 2025-08-22:
Hi :)

Please let me know if this/part of this issue should be moved to [probe-rs/hs-probe](https://github.com/probe-rs/hs-probe).

I see there is a nice comparison table in the README, however [probe-rs/hs-probe](https://github.com/probe-rs/hs-probe) is missing. What is the difference between that and rusty-probe? I see USB 2.0 High-speed, might be 5V tolerant from what I can tell from a quick glance(?). What is the max speed, etc?

Now that the part shortage problems have calmed down(from my experience at least), are there any reason not to pick the hs-probe?

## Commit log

2022-01-24 Schematic done and routed
    [rs-probe.kicad_pcb, rs-probe.kicad_sch]
2022-02-05 Added pull down on SWDIO to not float, updated silk and adhesive
    [rs-probe.kicad_pcb, rs-probe.kicad_sch]
2022-02-14 Add some more pulldowns
    [rs-probe.kicad_pcb, rs-probe.kicad_sch]
2022-03-01 Fix PDF
    [rs-probe.kicad_pcb, rs-probe.kicad_sch]
2022-03-03 Minor cleanup and MFPN fixes
    [rs-probe.kicad_pcb, rs-probe.kicad_sch]
2022-03-07 RevB, one more LDO to run the level translators
    [rs-probe.kicad_pcb, rs-probe.kicad_sch]
2022-03-09 Rev.D, now with it's own control of the level shifters' voltage
    [rs-probe-B_Cu.gbr, rs-probe-B_Mask.gbr, rs-probe-B_Paste.gbr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]
2022-03-10 Moved to 10 pin connector
    [rs-probe.kicad_pcb, rs-probe.kicad_sch]
2022-04-08 Push missing changes
    [rs-probe.kicad_pcb, rs-probe.kicad_sch]
2022-09-30 added LCSC PN for all symbols
    [rs-probe.kicad_sch]
2022-10-09 Move VCP pins so they are actually connected to an UART
    [rs-probe.kicad_pcb, rs-probe.kicad_sch]
2022-11-28 Updated LDOs, added CI/CD
    [rs-probe.kicad_pcb, rs-probe.kicad_sch]
2022-11-28 Fix reverse leakage on T_VCC, add git marker
    [rs-probe.kicad_pcb, rs-probe.kicad_sch]
2022-11-28 Preparing for panelization
    [rs-probe.kicad_pcb, rs-probe.kicad_sch]
2022-11-28 Added PI filter to input power rail
    [rs-probe.kicad_pcb, rs-probe.kicad_sch]
2022-11-29 Update tabs to > 3mm
    [rs-probe.kicad_pcb, rs-probe.kicad_sch]
2022-11-29 Fix missing 3D models
    [rs-probe.kicad_pcb]
2022-12-07 Consolidate to only use one LDO
    [rs-probe.kicad_pcb, rs-probe.kicad_sch]
2022-12-07 Update button model
    [rs-probe.kicad_pcb]
2023-03-31 Update for new JLCPCB limits
    [rs-probe.kicad_pcb]
2023-03-31 Fix DRCs due to new JLCPCB
    [rs-probe.kicad_pcb]
2023-11-09 Save for production
    [bom.csv, designators.csv, positions.csv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]
2023-11-12 Fix the kibot, update README, move production files to have date
    [bom.csv, designators.csv, positions.csv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]
2024-04-30 Update README.md on Target support desciption
    Changed probe comparison chart to be more accurate.
2024-11-12 build: 🛠 Add artifact publishing to releases
2024-12-06 Fix CI errors by moving to KiCAD 8
    [rs-probe.kicad_pcb, rs-probe.kicad_sch]
2024-12-06 fix: 🐛 Zip up produced artifacts
2026-02-17 Update pico information on table
